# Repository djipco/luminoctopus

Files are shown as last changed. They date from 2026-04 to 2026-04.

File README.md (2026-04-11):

# Luminoctopus

## Introduction

This repository hosts the **Luminoctopus** firmware as well as a component to control the device 
from [TouchDesigner](https://derivative.ca/). The Luminoctopus is an 8-channel LED controller that 
uses a fast serial-over-USB connection. It makes it easy to pilot RGB or RGBW LED arrays, strips or 
matrices (WS2811 / WS2812 / WS2812B / WS2813).

At its core, it uses an [OctoWS2811](https://www.pjrc.com/store/octo28_adaptor.html)-enabled 
[Teensy 4.1](https://www.pjrc.com/store/teensy41.html) board. 

> [!CAUTION]  
> _This is alpha software and might not be production ready. I'm having good success with it but 
> your mileage may vary. Report issues if you find any. Cheers!_

## How many LEDs can be controlled?

This project allows you to reliably control a maximum of 1365 addressable RGB LEDs per channel at a 
refresh rate of 24Hz. This yields a total of 10 920 LEDs for all 8 channels. At higher refresh rates, 
the maximum number of LEDs per channel decreases. For example, at approximately **30 Hz**, the 
practical limit is about **1 101 RGB LEDs per channel** (8 808 total). These thresholds apply to 
standard 800kHz RGB LEDs. If you use 400kHz LEDs, you will get half those numbers. 

| LED Type | Color Components | Max LEDs per Channel | Channels | **Max Total LEDs** | **Max Refresh Rate (approx.)** |
| --- | --- | --- | --- | --- | --- |
| WS2811 / WS2812 (RGB) | 3 (R, G, B) | **1 365** | 8 | **10 920** | **≈ 24 Hz** |
| WS2812B‑RGBW (RGBW) | 4 (R, G, B, W) | **1 023** | 8 | **8 184** | **≈ 24 Hz** |

The maximum number of supported LEDs depend on desired refresh rate, type of LED (RGB vs. RGBW), and
protocol speed (400kHz vs. 800kHz). There is a **hard maximum of 1365 RGB LEDs and 1023 RGBW LEDs 
per channel** (no matter the refresh rate). This is due to limits imposed by the size of a single 
DMA transfer (32kbits) on the microcontroller.

> [!NOTE]  
> _To help you figure out the usable maximum, the TouchDesigner component computes and displays the 
> maximum number of LEDs per channel given the currently selected settings._

To be on the safe side, you should use USB 2.0 or more recent. Luminoctopus connects at either **USB 
1.1 Full Speed** (12Mbits/s) or **USB 2.0 High Speed** (480Mbits/s). To update 1365 LEDs on each of 
the 8 channels, it must send about 44KB of data. To do this at 30Hz, it needs a bandwidth of 
1250KB/s (~10Mbps). This is below the 12 Mbps limit of USB 1.1 Full Speed, but leaves little 
headroom. For maximum reliability, USB 2.0 High Speed is strongly recommended.

## How can I use it?

#### Firmware

If it has not already been installed, you will need to install the firmware on the Luminoctopus 
device. To do so, use the [Arduino IDE](https://www.arduino.cc/en/software/) to upload the 
`Luminoctopus.ino` sketch to the device (from the `firmware/Luminoctopus/` folder).

> [!NOTE]
> To update the firmware on the Luminoctopus, you need to install the Teensy board extension (if not
> present) in the Arduino IDE. To do so, follow these
> [instructions](https://www.pjrc.com/teensy/td_download.html). 

#### TouchDesigner Component

As of now, the only library available is for the TouchDesigner environment. You can find the 
`Luminoctopus.tox` file in `libraries/touchdesigner/`. To use it, simply drag and drop the `.tox` 
file to your project and enter the appropriate settings.

Then, you can connect a TOP's output to each of the Luminoctopus' input channels and the colors from
the TOP will be applied to the LEDs connected to the device. If you want a 1-to-1 correspondance, 
use a TOP with a resolution of 1px high and Npx wide, where N is the number of LEDs in your LED 
strip.

## Luminoctopus Outputs

The layout for the two RJ-45 output ports on the Luminoctopus are as follows (for details, check 
out the documentation for the [OctoWS2811 adapter](https://www.pjrc.com/store/octo28_adaptor.html)):

|Port A (top) | Port B (bottom) |
|---|---|
| 0. Orange | 4. Orange |
| 1. Blue | 5. Blue |
| 2. Green | 6. Green |
| 3. Brown | 7. Brown |

Note that, within each of the Ethernet cable's twisted pairs, usually, the full-color wire is for 
data and the color+white wire is for ground (GND). 

## Hardware

If you want to build your own Luminoctopus, you will need to buy the following parts and do a bit of
soldering:

* [Teensy 4.1+](https://www.digikey.ca/short/z5vbzdh8) Microcontroller (Teensy 4.0 should also work, but has not been tested)
* [OctoWS2811 Adapter](https://www.digikey.ca/short/rcqpt3h0) for Teensy 4.x
* [Double Insulated Header Pins](https://www.digikey.ca/short/84fpr8q7)
* [14 Pins Socket](https://www.digikey.ca/short/hmf83qpt), 2.54mm Spacing
* Any Micro-B USB to USB Type B cable
* Any RJ-45 Ethernet Cable (cut in two and expose the 4 internal wire pairs)

The PJRC team has put together a [page](https://www.pjrc.com/store/octo28_adaptor.html) with 
detailed assembly and wiring information.

You can also 3D-print this [nice case](https://github.com/djipco/luminoctopus/tree/main/enclosure)
with removable cover (available as a single Autodesk Fusion file or two `.stl` files (thanks to Alexandre 
Labrie!)

## Protocol

This is advanced information about the binary format used to send commands to Luminoctopus using its 
native protocol.

> [!IMPORTANT]  
> _If you just want to use the device and library, you do not need to read anything beyond this 
> point. However, if you want to use or understand the protocol itself, you will find some info 
> below._

#### General Message Format

This is the general message format. **Length** identifies the length of the payload. For commands 
that do not have a payload (such as **Update**), the length is omitted. The checksum is always
present and occupies **2 bytes** (little-endian). Currently, it is computed as the modulo-256 of
`command` + `payload length` + `payload`, stored in the low byte (the high byte is reserved for a
future CRC-16 upgrade).

|START MARKER |COMMAND |PAYLOAD LENGTH |PAYLOAD |CHECKSUM |
|---|---|---|---|---|
|**1 byte**<br>(`0x00`)|**1 byte**<br>(`0x01` to `0xFF`)|**2 bytes**<br>(omitted for certain commands)|**variable length**<br>(omitted for certain commands)|**2 bytes**<br>(`LSB` + `0x00`) |

#### Currently Available Commands

* **Get Info** (`0x01`)
* **Get Config** (`0x02`)
* **Configure** (`0x20`)
* **Assign Colors** (`0x40`)
* **Fill Color** (`0x41`)
* **Update** (`0x60`)

#### Get System Information

The **Get System Information** command allows a client to query the device for its identity and 
protocol compatibility. It is primarily used during connection establishment (handshake), but may 
be sent at any time. The device automatically sends an `INFO` response once the serial connection 
is established.

|START MARKER|COMMAND|CHECKSUM |
|---|---|---|
|`0x00` |`0x01` | 2 bytes |

#### Response Format

The device replies with a **single ASCII line**, prefixed with `INFO:` and terminated by a newline
(`\n`):

    INFO: DEVICE=<name> PROTOCOL=<version> FIRMWARE=<version> CHANNELS=<count> TRANSPORT=<transport>

For example:

    INFO: DEVICE=Luminoctopus PROTOCOL=1 FIRMWARE=1.0.0-alpha.9 CHANNELS=8 TRANSPORT=USB

Clients **must ignore unknown fields** to remain forward‑compatible.

#### Get Configuration

The **Get Configuration** command allows a client to query the device's current configuration.

|START MARKER|COMMAND|CHECKSUM |
|---|---|---|
|`0x00` |`0x02` | 2 bytes |

The device replies with a **single ASCII line**, prefixed with `CONFIG:` and terminated by a newline
(`\n`):

    CONFIG: COLOR_ORDER=<order> SPEED=<speed> LEDS_PER_CHANNEL=<count>

For example:

    CONFIG: COLOR_ORDER=GRB SPEED=800kHz LEDS_PER_CHANNEL=300

#### Configure Device Command

This is usually the first command sent since it allows to specify the type of LEDs you wish to 
control, the protocol speed and the number of LEDs per channel. If this command is not sent, the 
device is configured by default to use 300 LEDs per channel, using GRB order, and a speed of 800kHz.

|START MARKER|COMMAND|PAYLOAD LENGTH|COLOR ORDER|SPEED |LEDS PER CHANNEL|CHECKSUM |
|---|---|---|---|---|---|---|
|`0x00` |`0x20` |`0x00` `0x04` |  1 byte | 1 byte | 2 bytes | 2 bytes |

Available color orders are:

  * WS2811_RGB  =  0 (`0x00`)
  * WS2811_RBG  =  1 (`0x01`)
  * WS2811_GRB  =  2 (`0x02`)
  * WS2811_GBR  =  3 (`0x03`)
  * WS2811_BRG  =  4 (`0x04`)
  * WS2811_BGR  =  5 (`0x05`)
  * WS2811_RGBW =  6 (`0x06`)
  * WS2811_RBGW =  7 (`0x07`)
  * WS2811_GRBW =  8 (`0x08`)
  * WS2811_GBRW =  9 (`0x09`)
  * WS2811_BRGW = 10 (`0x0A`)
  * WS2811_BGRW = 11 (`0x0B`)
  * WS2811_WRGB = 12 (`0x0C`)
  * WS2811_WRBG = 13 (`0x0D`)
  * WS2811_WGRB = 14 (`0x0E`)
  * WS2811_WGBR = 15 (`0x0F`)
  * WS2811_WBRG = 16 (`0x10`)
  * WS2811_WBGR = 17 (`0x11`)
  * WS2811_RWGB = 18 (`0x12`)
  * WS2811_RWBG = 19 (`0x13`)
  * WS2811_GWRB = 20 (`0x14`)
  * WS2811_GWBR = 21 (`0x15`)
  * WS2811_BWRG = 22 (`0x16`)
  * WS2811_BWGR = 23 (`0x17`)
  * WS2811_RGWB = 24 (`0x18`)
  * WS2811_RBWG = 25 (`0x19`)
  * WS2811_GRWB = 26 (`0x1A`)
  * WS2811_GBWR = 27 (`0x1B`)
  * WS2811_BRWG = 28 (`0x1C`)
  * WS2811_BGWR = 29 (`0x1D`)

Available speeds are: 

  * WS2811_800kHz =   0 (`0x00`)
  * WS2811_400kHz =  64 (`0x40`)
  * WS2813_800kHz = 128 (`0x80`)

The number of LEDs per channel must be 1365 or less for RGB and 1023 or less for RGBW. Two bytes are
used to express this number.

#### Assign Colors Command

This command allows individual assignment of the color of all LEDs on a channel. If the controller 
has been configured to use 4-component colors (RGBW), you can send 4 bytes per color. Otherwise, it 
defaults to 3 bytes (RGB).

|START MARKER|COMMAND|PAYLOAD LENGTH|PAYLOAD |CHECKSUM |
|---|---|---|---|---|
|`0x00` |`0x40` | 2 bytes |Channel number + 3 (or 4) bytes for each LED's color| 2 bytes |

#### Fill Color Command

This assigns the same color to all the LEDs on a channel (or all channels, if channel `255` is 
specified). It can be used to turn off the lights by sending a color of (0, 0, 0).

|START MARKER|COMMAND|PAYLOAD LENGTH|PAYLOAD |CHECKSUM |
|---|---|---|---|---|
|`0x00` |`0x41` | 2 bytes |Channel number + R + G + B (or R+G+B+W)| 2 bytes |

#### Update Command

After assigning colors with **Assign** or **Fill**, you must send the **Update** message to trigger 
the actual update of the LEDs. This allows you to prepare more than one channel beforehand and 
synchronize their update to happen at the same time.

|START MARKER|COMMAND|CHECKSUM |
|---|---|---|
|`0x00` |`0x60` | 2 bytes |

This command always updates all 8 channels.

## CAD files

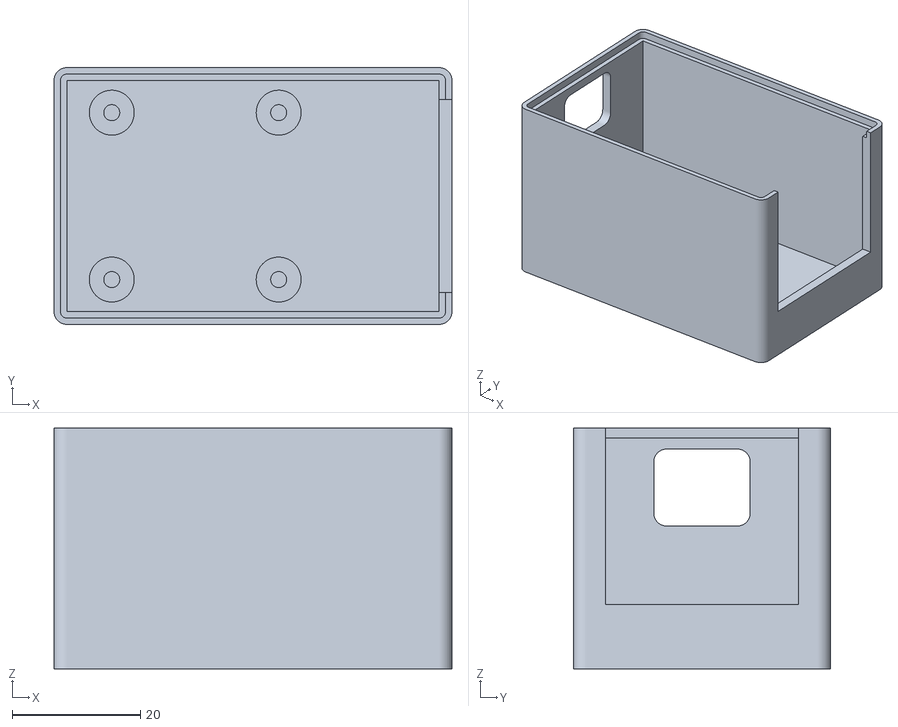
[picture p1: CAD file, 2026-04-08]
enclosure/enclosure.stl
62.0 x 40.0 x 37.5

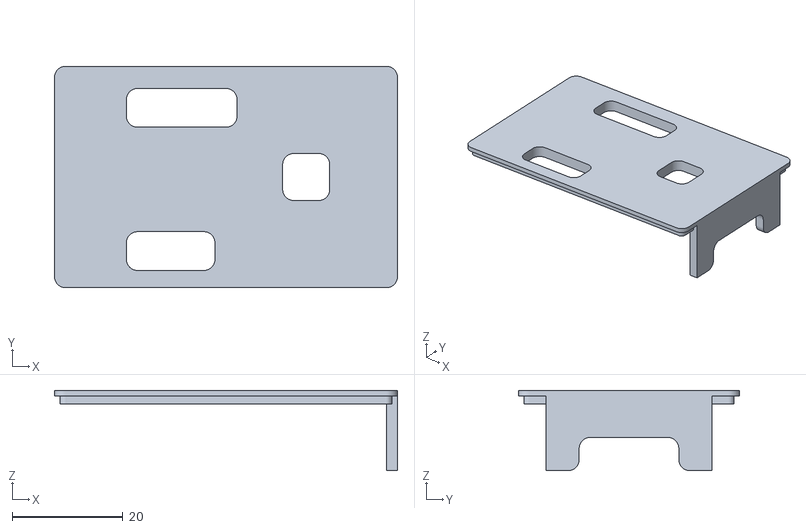
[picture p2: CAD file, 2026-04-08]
enclosure/cover.stl
62.0 x 40.0 x 14.5

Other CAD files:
enclosure/enclosure.f3d

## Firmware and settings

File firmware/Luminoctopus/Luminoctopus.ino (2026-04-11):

/*
  ==================================================================================================
   
   LUMINOCTOPUS
   © 2025-2026, Jean-Philippe Côté (djip.co)

   GNU General Public License v3.0

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
  ==================================================================================================
*/

// The Luminoctopus firmware uses the OctoWS2811 LED Library by Paul Stoffregen which is freely
// available on GitHub (no license specified): https://github.com/PaulStoffregen/OctoWS2811
#include <OctoWS2811.h>

// Debugging flag
#define DEBUG 0

// Library name and version
constexpr const char* LIB_NAME                  = "Luminoctopus";
constexpr const char* LIB_VERSION               = "1.0.0-alpha.10";

// Protocol version
constexpr uint8_t PROTOCOL_VERSION              = 1;

// General constants
constexpr uint8_t  BROADCAST_CHANNEL            =    255; // 255 => "broadcast to all channels"
constexpr uint8_t  BUFFER_MULTIPLIER            =      6; // Multiplier for buffer
constexpr uint8_t  CHANNEL_COUNT                =      8; // Number of channels available on device
constexpr uint16_t CHECKSUM_MODULO              =    256; // Modulo for checksum
constexpr uint16_t DEFAULT_CHANNEL_COUNT        =    300; // Default number of LEDs per channel
constexpr uint16_t MAX_PAYLOAD                  =   8192; // Max payload size (in bytes)
constexpr uint16_t MAX_RGB_LEDS_PER_CHANNEL     =   1365; // Hardware limit due to DMA transfer speed
constexpr uint16_t MAX_RGBW_LEDS_PER_CHANNEL    =   1023; // Hardware limit due to DMA transfer speed
constexpr uint8_t  SOF_MARKER                   =   0x00; // Start of frame marker
constexpr uint16_t SYSTEM_ID                    = 0x0001; // Luminoctopus system ID (0x00 0x01)

// Commands (0x00 is reserved for SOF)
constexpr uint8_t CMD_GET_INFO                  = 0x01; // Query commands (0x01–0x1F)
constexpr uint8_t CMD_GET_CONFIG                = 0x02;
constexpr uint8_t CMD_CONFIGURE                 = 0x20; // Configuration commands (0x20–0x3F)
constexpr uint8_t CMD_ASSIGN_COLORS             = 0x40; // LED data commands (0x40–0x5F)
constexpr uint8_t CMD_FILL_COLOR                = 0x41;
constexpr uint8_t CMD_UPDATE                    = 0x60; // Control commands (0x60–0x7F)
// 0x80–0x9F (reserverd)
// 0xA0–0xBF (reserverd)
// 0xC0–0xDF (reserverd)
constexpr uint8_t CMD_SYSTEM_EXCLUSIVE          = 0xE0; // System-exclusive commands (0xE0–0xFF)

// Error codes
constexpr uint8_t ERR_UNKNOWN_COMMAND           = 0x01; // Query errors (0x01–0x1F)
constexpr uint8_t ERR_PAYLOAD_TOO_SHORT         = 0x20; // Configuration errors (0x20–0x3F)
constexpr uint8_t ERR_INVALID_COLOR_ORDER       = 0x21;
constexpr uint8_t ERR_INVALID_SPEED             = 0x22;
constexpr uint8_t ERR_INVALID_LED_COUNT         = 0x23;
constexpr uint8_t ERR_INVALID_CHANNEL           = 0x40; // LED data errors (0x40–0x5F)
constexpr uint8_t ERR_COLOR_COMPONENT_MISMATCH  = 0x41;
constexpr uint8_t ERR_SYSTEM_NOT_INITIALIZED    = 0xE0; // System errors (0xE0–0xFF)
constexpr uint8_t ERR_PAYLOAD_TOO_LARGE         = 0xE1;
constexpr uint8_t ERR_CHECKSUM_MISMATCH         = 0xE2;


// Map of allowed color orders using OctoWS2811's constants 
const int colorOrderMap[] = {
  WS2811_RGB,   //  0
  WS2811_RBG,   //  1
  WS2811_GRB,   //  2 (default)
  WS2811_GBR,   //  3
  WS2811_BRG,   //  4
  WS2811_BGR,   //  5
  WS2811_RGBW,  //  6
  WS2811_RBGW,  //  7
  WS2811_GRBW,  //  8
  WS2811_GBRW,  //  9
  WS2811_BRGW,  // 10
  WS2811_BGRW,  // 11
  WS2811_WRGB,  // 12
  WS2811_WRBG,  // 13
  WS2811_WGRB,  // 14
  WS2811_WGBR,  // 15
  WS2811_WBRG,  // 16
  WS2811_WBGR,  // 17
  WS2811_RWGB,  // 18
  WS2811_RWBG,  // 19
  WS2811_GWRB,  // 20
  WS2811_GWBR,  // 21
  WS2811_BWRG,  // 22
  WS2811_BWGR,  // 23
  WS2811_RGWB,  // 24
  WS2811_RBWG,  // 25
  WS2811_GRWB,  // 26
  WS2811_GBWR,  // 27
  WS2811_BRWG,  // 28
  WS2811_BGWR   // 29
};

// Number of available color orders
constexpr int COLOR_ORDER_COUNT = sizeof(colorOrderMap) / sizeof(colorOrderMap[0]);

// Actual names for the color orders
const char* colorOrderNames[] = {
  "RGB", "RBG", "GRB", "GBR", "BRG", "BGR", "RGBW", "RBGW", "GRBW", "GBRW", "BRGW", "BGRW", "WRGB",
  "WRBG", "WGRB", "WGBR", "WBRG", "WBGR", "RWGB", "RWBG", "GWRB", "GWBR", "BWRG", "BWGR", "RGWB",
  "RBWG", "GRWB", "GBWR", "BRWG", "BGWR"
};

// State
uint8_t componentsPerPixel = 3;                       // 3 for RGB, 4 for RGBW
bool connected = false;                               // Whether serial is connected
uint8_t checksumState = 0;                            // Data used to calculate checksum
uint8_t cmd = 0;                                      // Identified command
bool frameReady = false;                              // Whether a new frame is ready to display
bool isRGBW = false;                                  // Whether we are using 4-channel LEDs
uint16_t ledsPerChannel = MAX_RGBW_LEDS_PER_CHANNEL;  // Number of LEDs per channel
uint16_t len = 0;                                     // Length of payload
uint8_t chkL = 0;

uint8_t currentColorOrder = 2;                        // Currently configured color order (GRB by default)
uint8_t currentSpeed = WS2811_800kHz;                 // Currently configured speed (WS2811_800kHz by default)

enum class ParseState : uint8_t {                     // Serial parser state machine
  WAIT_SOF,
  READ_CMD,
  READ_LEN1,
  READ_LEN2,
  READ_DATA,
  READ_CHK,
  READ_CHK2
};

ParseState state = ParseState::WAIT_SOF;              // Current state
uint8_t payload[MAX_PAYLOAD];                         // Byte array for the payload
uint16_t payloadIndex = 0;                            // Position of next byte to write in payload

constexpr uint16_t MAX_LEDS = MAX_RGB_LEDS_PER_CHANNEL;
constexpr size_t MAX_BUFFER_SIZE = MAX_LEDS * BUFFER_MULTIPLIER * sizeof(int);

// Buffers are statically allocated for the maximum supported LED count to guarantee deterministic 
// behavior and avoid heap fragmentation.
int dmaBufferStatic[MAX_BUFFER_SIZE / sizeof(int)];
int drawBufferStatic[MAX_BUFFER_SIZE / sizeof(int)];

// Debugging
#if DEBUG
elapsedMillis timer;
bool busy = false;
#endif

// Storage for placement-new OctoWS2811 instance (properly aligned)
alignas(OctoWS2811) static uint8_t octoStorage[sizeof(OctoWS2811)];
OctoWS2811* leds = nullptr;

void createOctoWS2811Instance(uint16_t ledCount, int configFlags) {

  // Destroy previous instance if it exists
  if (leds) {
    leds->~OctoWS2811();
    leds = nullptr;
  }
  
  // Clear buffers to avoid stale LED data after reconfiguration
  memset(dmaBufferStatic, 0, MAX_BUFFER_SIZE);
  memset(drawBufferStatic, 0, MAX_BUFFER_SIZE);

  // Construct in preallocated storage
  leds = new (octoStorage) OctoWS2811(
    ledCount,
    dmaBufferStatic,
    drawBufferStatic,
    configFlags
  );

}

void configure(
  uint8_t order = 2,
  uint8_t speed = WS2811_800kHz, 
  uint16_t ledCount = DEFAULT_CHANNEL_COUNT
) {

  if (!isValidColorOrder(order)) {
    sendError(ERR_INVALID_COLOR_ORDER, "COLOR_ORDER_NOT_SUPPORTED");
    return;
  }

  if (!isValidSpeed(speed)) {
      sendError(ERR_INVALID_SPEED, "PROTOCOL_SPEED_NOT_SUPPORTED");
      return;
  }

  bool is4 = (colorOrderMap[order] >= WS2811_RGBW);
  uint16_t maxLeds = is4 ? MAX_RGBW_LEDS_PER_CHANNEL : MAX_RGB_LEDS_PER_CHANNEL;
    
  if (ledCount == 0 || ledCount > maxLeds) {
    sendError(ERR_INVALID_LED_COUNT, "LEDS_PER_CHANNEL_OUT_OF_RANGE");
    return;
  }

  // Create new OctoWS2811 instance with the requested configuration
  createOctoWS2811Instance(ledCount, colorOrderMap[order] | speed);

  // Update global state
  currentColorOrder  = order;
  currentSpeed       = speed;
  ledsPerChannel = ledCount;
  isRGBW = (colorOrderMap[order] >= WS2811_RGBW);
  componentsPerPixel = isRGBW ? 4 : 3;
  
  // Initialize OctoWS2811 object with the requested configuration and tell loop() to update
  leds->begin();
  frameReady = true; 

}

void setup() {

  // On the Teensy, the USB hardware initialization happens before setup() is run and the baud rate 
  // used is always the full native USB speed (either 12 or 480 Mbit/sec). So, there is no need to 
  // call Serial.begin(). Details: https://www.pjrc.com/teensy/td_serial.html

  createOctoWS2811Instance(DEFAULT_CHANNEL_COUNT, WS2811_GRB | WS2811_800kHz);

}

void loop() {

  // Wait for remote software to open serial connection. When it has, perform configuration and send
  // confirmation.
  if (Serial.dtr()) {
    if (!connected) {
      connected = true;
      configure();
      handleGetInfoCommand();
    } 
  } else {

    if (connected) {
      connected = false;
      resetParser();
      frameReady = false;
    }
    delay(20); 
    return;

  }
  
  // Read incoming serial data (if any)
  while (Serial.available()) {
    readSerialByte(Serial.read());
  }
  
  // Performance debugging
  #if DEBUG
    if (leds && leds->busy()) {
      if (!busy) {
        busy = true;
        timer = 0;
      }
    } else {
      if (busy) {
        busy = false;
        Serial.print("Update: ");
        Serial.print(timer);
        Serial.println("ms");
        timer = 0;
      }
    }
  #endif

  // If frame data is ready, update the LEDs. We wait for leds.busy() to be false. However, this may
  // cause dropped frames if too much data is pushed. That's why the client must respect the limits.
  if (frameReady && leds && !leds->busy()) {
    leds->show();
    frameReady = false;
  }

}

void readSerialByte(uint8_t b) {

  switch (state) {

    // Wait for start of frame marker
    case ParseState::WAIT_SOF:
      if (b == SOF_MARKER) state = ParseState::READ_CMD;
      break;
      
    // Read command byte
    case ParseState::READ_CMD:

      cmd = b;
      checksumState = b;

      // For zero-payload commands, we jump ahead to READ_CHK.
      if (cmd == CMD_UPDATE || cmd == CMD_GET_INFO || cmd == CMD_GET_CONFIG) {
        len = 0;
        state = ParseState::READ_CHK;
      } else {
        state = ParseState::READ_LEN1;
      }

      break;
      
    // Get first byte of payload length
    case ParseState::READ_LEN1:
      len = b;
      checksumState += b;
      state = ParseState::READ_LEN2;
      break;
      
    // Get second byte of payload length, and compute final length
    case ParseState::READ_LEN2:
      len |= (b << 8);
      checksumState += b;
      if (len > MAX_PAYLOAD) {
        state = ParseState::WAIT_SOF;
        checksumState = 0;
        sendError(ERR_PAYLOAD_TOO_LARGE, "MAX_PAYLOAD_EXCEEDED");
      } else {
        payloadIndex = 0;
        state = ParseState::READ_DATA;
      }
      break;
      
    // Read full payload
    case ParseState::READ_DATA:
      payload[payloadIndex++] = b;
      checksumState += b;
      if (payloadIndex >= len) state = ParseState::READ_CHK;
      break;
      
    // Verify checksum
    case ParseState::READ_CHK:
      // if (checksumState % CHECKSUM_MODULO == b) {
      //   processCommand();
      // } else {
      //   checksumState = 0;
      //   sendError(ERR_CHECKSUM_MISMATCH, "CHECKSUM_VERIFICATION_FAILED");
      // }
      // state = ParseState::WAIT_SOF;
      // break;
      chkL = b;              // stocker le premier octet, vérifier au prochain
      state = ParseState::READ_CHK2;
      break;

    case ParseState::READ_CHK2: {
      uint16_t received = chkL | (b << 8);
      uint16_t expected = checksumState % CHECKSUM_MODULO;  // MSB = 0x00 pour l'instant

      if (received == expected) {
        processCommand();
      } else {
        checksumState = 0;
        sendError(ERR_CHECKSUM_MISMATCH, "CHECKSUM_VERIFICATION_FAILED");
      }
      state = ParseState::WAIT_SOF;
      break;
    }

  }
  
}

void processCommand() {

    switch (cmd) {
      
      case CMD_GET_INFO:      handleGetInfoCommand();      break;
      case CMD_CONFIGURE:     handleConfigureCommand();    break;
      case CMD_GET_CONFIG:    handleGetConfigCommand();    break;
      case CMD_ASSIGN_COLORS: handleAssignColorsCommand(); break;
      case CMD_FILL_COLOR:    handleFillColorCommand();    break;
      case CMD_UPDATE:        handleUpdateCommand();       break;
      default:
        sendError(ERR_UNKNOWN_COMMAND, "COMMAND_NOT_SUPPORTED");
        break;
    }

}

void handleGetInfoCommand() {

  Serial.print("INFO: ");

  Serial.print("DEVICE=");
  Serial.print(LIB_NAME);

  Serial.print(" PROTOCOL=");
  Serial.print(PROTOCOL_VERSION);

  Serial.print(" FIRMWARE=");
  Serial.print(LIB_VERSION);

  Serial.print(" CHANNELS=");
  Serial.print(CHANNEL_COUNT);

  Serial.println(" TRANSPORT=USB");

}

void handleGetConfigCommand() {

  Serial.print("CONFIG: ");

  Serial.print("COLOR_ORDER=");
  Serial.print(colorOrderNames[currentColorOrder]);

  Serial.print(" SPEED=");
  switch (currentSpeed) {
    case WS2811_800kHz: Serial.print("800kHz"); break;
    case WS2811_400kHz: Serial.print("400kHz"); break;
    case WS2813_800kHz: Serial.print("800kHz_WS2813"); break;
    default:            Serial.print("UNKNOWN"); break;
  }

  Serial.print(" LEDS_PER_CHANNEL=");
  Serial.print(ledsPerChannel);

  Serial.println();

}

void sendError(uint8_t errCode, const char* message) {
  Serial.print("ERROR: CODE=0x");
  Serial.print(errCode, HEX);
  Serial.print(" MESSAGE=");
  Serial.println(message);
}

void handleConfigureCommand() {

  // We leave for the possibility of a larger length to allow future extensions in the configuration
  // options.
  if (len < 4) {
    sendError(ERR_PAYLOAD_TOO_SHORT, "PAYLOAD_TOO_SHORT");
    return;
  }
  
  // Read color order and speed
  uint8_t colorOrder = payload[0];
  uint8_t speed = payload[1];

  // Read LED count
  uint16_t count = payload[2] | (payload[3] << 8);

  // Validate if color order, speed and count are valid
  bool validColor = isValidColorOrder(colorOrder);
  bool validSpeed = isValidSpeed(speed);

  // Validate LED count (depends on component count)
  bool validLedCount;

  if (validColor && colorOrderMap[colorOrder] >= WS2811_RGBW) {
    validLedCount = (count > 0 && count <= MAX_RGBW_LEDS_PER_CHANNEL);
  } else {
    validLedCount = (count > 0 && count <= MAX_RGB_LEDS_PER_CHANNEL);
  }
  
  if (!validColor) {
    sendError(ERR_INVALID_COLOR_ORDER, "COLOR_ORDER_NOT_SUPPORTED");
  }

  if (!validSpeed) {
    sendError(ERR_INVALID_SPEED, "PROTOCOL_SPEED_NOT_SUPPORTED");
  }

  if (!validLedCount) {
    sendError(ERR_INVALID_LED_COUNT, "LEDS_PER_CHANNEL_OUT_OF_RANGE");
  }
  
  if (validColor && validSpeed && validLedCount) {
    configure(colorOrder, speed, count);
    handleGetConfigCommand();
  }

}

void handleAssignColorsCommand() {

  if (!leds) {
    sendError(ERR_SYSTEM_NOT_INITIALIZED, "LED_SYSTEM_NOT_READY");
    return;
  }

  // Check payload format (RGB or RGBW)
  if ((len - 1) % componentsPerPixel != 0) {
    sendError(ERR_COLOR_COMPONENT_MISMATCH, "COLOR_COMPONENT_MISMATCH");
    return;
  }
  
  // First byte of payload is channel
  uint8_t ch = payload[0];
  if (ch >= CHANNEL_COUNT) {
    sendError(ERR_INVALID_CHANNEL, "CHANNEL_INDEX_OUT_OF_RANGE");
    return;
  }
  
  // Calculate number of LEDs in this payload
  uint16_t ledsInPayload = (len - 1) / componentsPerPixel;

  // Check if we're trying to write beyond the allocated LEDs
  if (ledsInPayload > ledsPerChannel) {
    #if DEBUG
    Serial.println("DEBUG: PAYLOAD_TOO_LARGE_IGNORED");
    #endif
    return;
  }
  
  // Prepare data and index for the loop
  const uint8_t* data = &payload[1];
  uint16_t index = ch * ledsPerChannel;
  
  // Check if we are dealing with 3 or 4 color components
  if (isRGBW) {
    for (uint16_t i = 0; i < ledsInPayload; i++) {
      leds->setPixel(index + i, data[0], data[1], data[2], data[3]);
      data += 4;
    }
  } else {
    for (uint16_t i = 0; i < ledsInPayload; i++) {
      leds->setPixel(index + i, data[0], data[1], data[2]);
      data += 3;
    }
  }

}

void handleFillColorCommand() {

  if (!leds) {
    sendError(ERR_SYSTEM_NOT_INITIALIZED, "LED_SYSTEM_NOT_READY");
    return;
  }
  
  if (len < (isRGBW ? 5 : 4)) {
    sendError(ERR_PAYLOAD_TOO_SHORT, "FILL_COLOR_PAYLOAD_TOO_SHORT");
    return;
  }
  
  // Channel
  uint8_t ch = payload[0];

  if (!isValidChannel(ch)) {
    sendError(ERR_INVALID_CHANNEL, "CHANNEL_INDEX_OUT_OF_RANGE");
    return;
  }

  // Color
  uint8_t r = payload[1];
  uint8_t g = payload[2];
  uint8_t b = payload[3];
  uint8_t w = isRGBW ? payload[4] : 0;
  
  // Check if we are dealing with RGB or RGBW, unique channel or broadcast, and update the LEDs.
  if (isRGBW) {
    if (ch == BROADCAST_CHANNEL) {
      for (int i = 0; i < CHANNEL_COUNT * ledsPerChannel; i++) {
        leds->setPixel(i, r, g, b, w);
      }
    } else if (ch < CHANNEL_COUNT) {
      for (int i = 0; i < ledsPerChannel; i++) {
        leds->setPixel(ch * ledsPerChannel + i, r, g, b, w);
      }
    }
  } else {
    if (ch == BROADCAST_CHANNEL) {
      for (int i = 0; i < CHANNEL_COUNT * ledsPerChannel; i++) {
        leds->setPixel(i, r, g, b);
      }
    } else if (ch < CHANNEL_COUNT) {
      for (int i = 0; i < ledsPerChannel; i++) {
        leds->setPixel(ch * ledsPerChannel + i, r, g, b);
      }
    }
  }

}

void handleUpdateCommand() {
  
  if (!leds) {
    sendError(ERR_SYSTEM_NOT_INITIALIZED, "LED_SYSTEM_NOT_READY");
    return;
  }

  frameReady = true; // Tells the main loop() to update

}

bool isValidChannel(uint8_t ch) {
  return ch < CHANNEL_COUNT || ch == BROADCAST_CHANNEL;
}

bool isValidColorOrder(uint8_t order) {
  return order < COLOR_ORDER_COUNT;
}

bool isValidSpeed(uint8_t speed) {
  return speed == WS2811_800kHz || speed == WS2811_400kHz || speed == WS2813_800kHz;
}

void resetParser() {
  state = ParseState::WAIT_SOF;
  payloadIndex = 0;
  len = 0;
  checksumState = 0;
  chkL = 0;
}

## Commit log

2025-07-17 Make max number of LEDs per channel configurable
2025-07-18 Add ability to black out all LEDs
2025-08-01 Fix modulo constant type
    [Luminoctopus.ino]
2026-04-04 Update port menu on device change
2026-04-06 Fix default value for configure's order parameter
    [Luminoctopus.ino]
2026-04-06 Add LED specifications table to README
    Added a table summarizing LED types, their color components, maximum LEDs per channel, and refresh rates.
2026-04-06 Update Teensy 4.1 compatibility note in README
    Clarified compatibility of Teensy 4.1 with Teensy 4.0 in the parts list.
2026-04-06 Update LED control and USB connection details in README
    Clarified maximum LED control limits and USB requirements for reliability.
2026-04-08 Update USB cable description
2026-04-08 Add enclosure 3D models
    [cover.stl, enclosure.f3d, enclosure.stl]
2026-04-08 Update 3D-printable case link
    Updated link for the 3D-printable case and removed placeholder.
2026-04-11 Add logging and device filtering
2026-04-11 Reset device filtering toggle after canceling install

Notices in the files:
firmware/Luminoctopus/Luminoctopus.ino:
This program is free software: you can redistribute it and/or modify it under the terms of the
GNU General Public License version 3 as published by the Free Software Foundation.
